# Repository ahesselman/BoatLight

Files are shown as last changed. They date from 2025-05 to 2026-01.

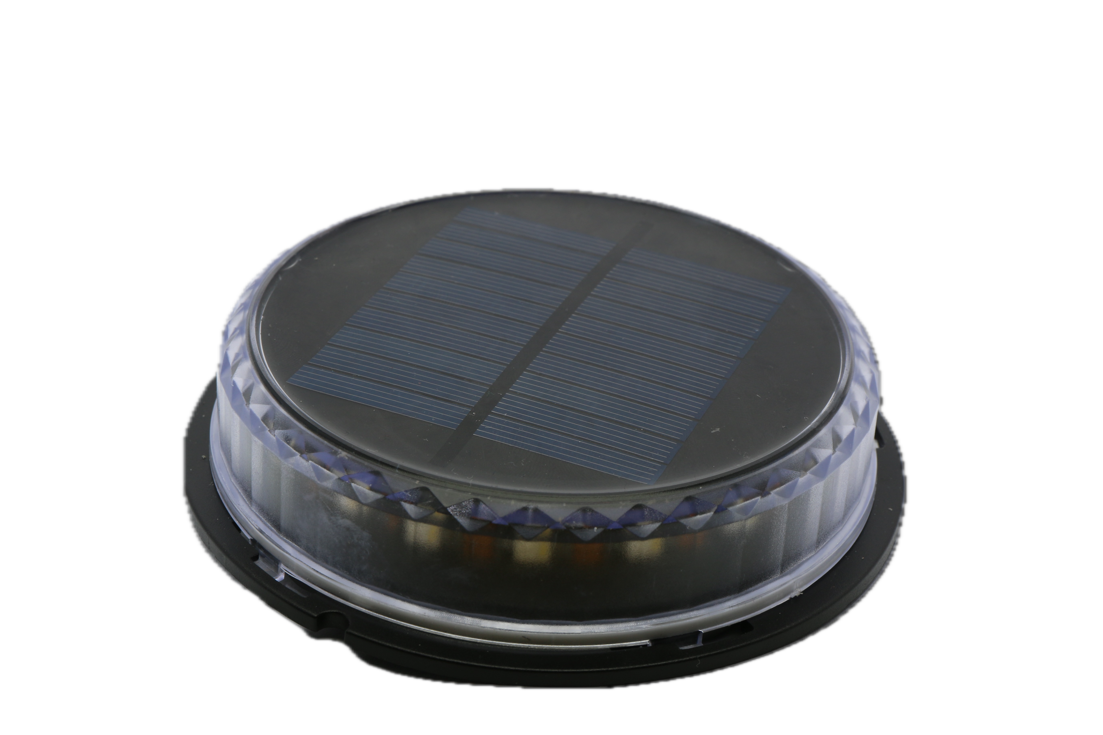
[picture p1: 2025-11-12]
Documents/Images/Lamp.png

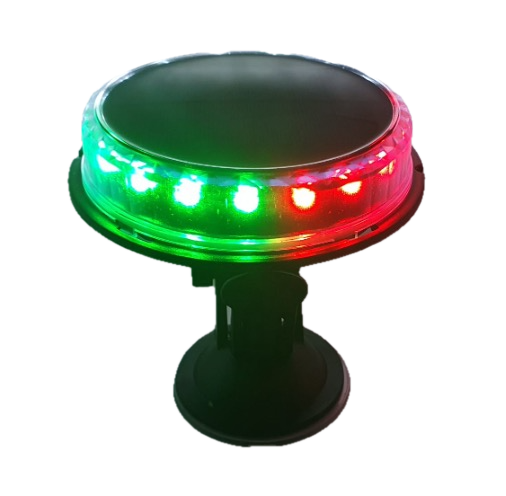
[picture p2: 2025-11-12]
Documents/Images/Lamp On.png

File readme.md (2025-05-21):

# Boat light controller

Controller for a boat light which indicates port and starboard. 

## Description

BoatLight is an LED ring system designed to indicate the port (red) and starboard (green) sides of a boat. It supports eight user-selectable modes, which can be toggled using a physical button. The currently selected mode is saved to persistent storage, so it resumes automatically after a power cycle.

The device is solar-powered. It monitors the voltage from a connected solar panel to determine whether it should be active or idle. When the solar panel voltage drops below 2.35V, the device activates. When the voltage rises above 2.40V, the device enters an idle state to conserve power.

## System overview

* **Power source**: solar panel and USB input
* **Battery**: ?
* **Charging module**: TP4056 for battery charging management
* **Microcontroller**: ATTiny85 for controlling the LEDs and handling user input
* **LEDs**: 16 SK6812 addressable RGBW LEDs
* **User input**: Single push-button for mode selection
* **Power control**: P-channel MOSFET to switch LED power

### Power management

1. Charging circuit

* **TP4056 module**: Connect the solar panel and USB input through appropriate diodes to the TP4056 module's input.
* **Battery connection**: The battery connects to the BAT+ and BAT- terminals of the TP4056.

2. Load sharing

To allow the system to operate while charging and prevent the battery from supplying power when external sources are available, load sharing is implemented

3. Voltage monitoring

A voltage divider is used to monitor the solar panel voltage. This allows the ATTiny85 to detect when the solar voltage drops below 2.35 and activate the LEDs accordingly. To improve stability and prevent unwanted rapid switching, hysterisis is applied. 

### Control circuit

1. ATTiny85 Microcontroller

* **Power supply**: powered from the battery through a voltage regeulator (if necessary).

* **Inputs**:
    * **Voltage divider**: Connected to an ADC pin to monitor solar voltage.
    * **Push-button**: Connected to a digital input pin with a pull-up resistor for mode selection.

* **Outputs**:
    * **LED Control**: A digital output pin connected to the data line of the SK6812 LED strip.
    * **MOSFET control**: A digital output pin to control  the gate of the P-channel MOSFET, switching the LED POWER.

2. P-Channel MOSFET

Used to switch the power for the SK6812 LEDs. The gate is controlled by the the ATTiny85, allowing the microcontroller to disconnect power from the LEDs when not in use, conserving battery life.

## Getting Started

### Dependencies

* Adafruit_NeoPixel

### Setup

* https://www.instructables.com/How-to-Program-an-Attiny85-From-an-Arduino-Uno/

## Authors
LedOptions

### Executing program

## Version History

* 0.1
    * Initial release

## Acknowledgments

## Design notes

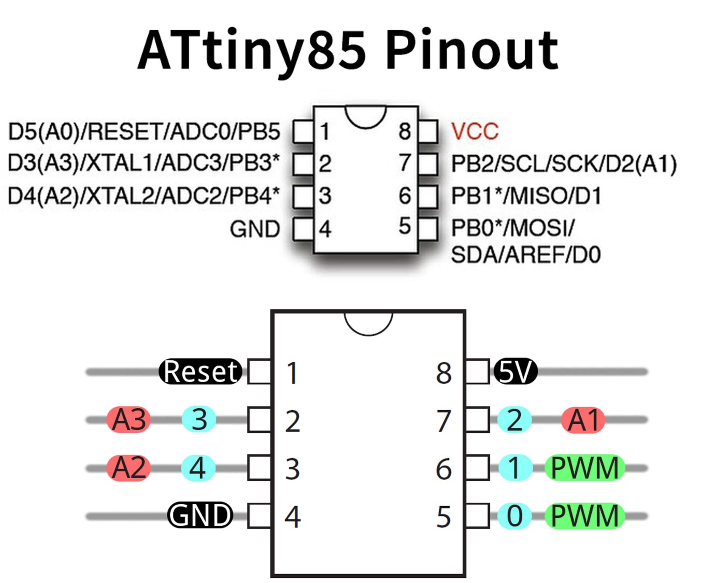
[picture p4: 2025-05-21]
Documents/Images/ATtiny85 pinout.jpg

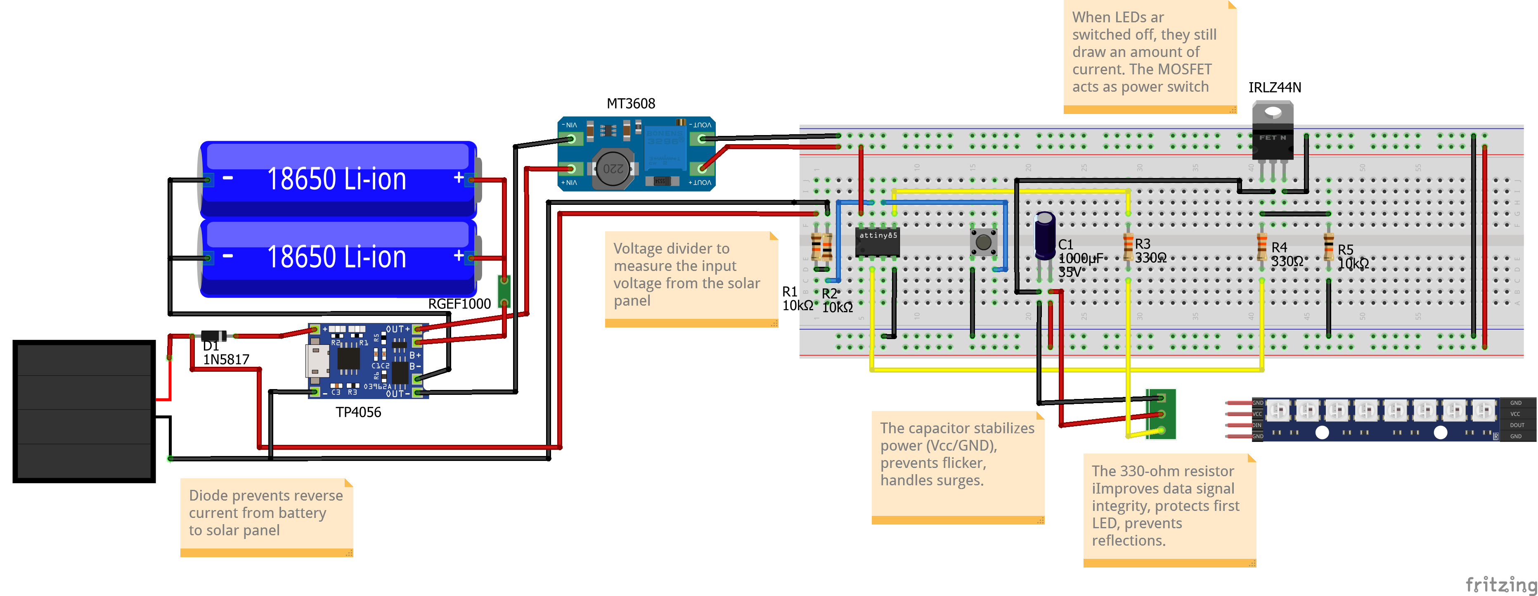
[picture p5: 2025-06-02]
Documents/Images/Sketch.png

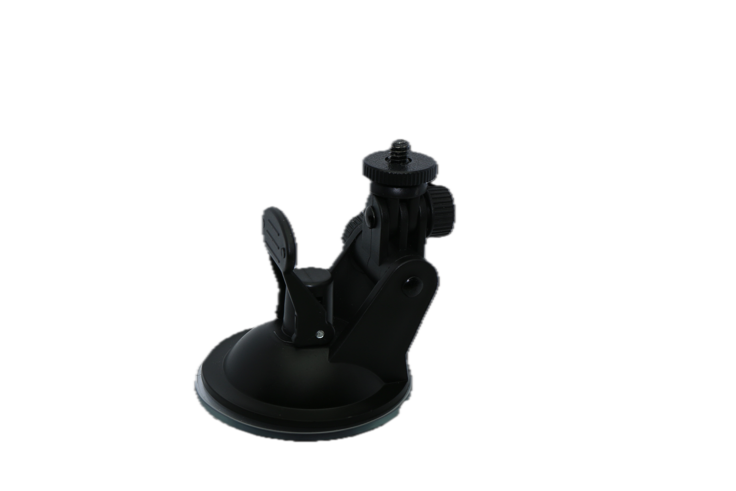
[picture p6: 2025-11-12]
Documents/Images/Stand.png

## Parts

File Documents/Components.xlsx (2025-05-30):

 |  |  |  |  | €23.70
Component | Module | Opmerking | Aantal | Prijs per stuk | Totaal
18650 Cell | Panasonic 3.7V 3200mAh Li-ion Nitecore NL1834 | Beveiliging tegen diepontlading | 2 | €8.95 | €17.90
Charge controller | CN3791 |  |  |  | €0.00
 |  |  |  |  | €0.00
 |  |  |  |  | €0.00
5V 3W zonnepaneel |  |  | 1 | €5.00 | €5.00
Zekering | MR-F110 |  | 1 | €0.80 | €0.80
 |  |  |  |  | €0.00
 |  |  |  |  | €0.00
 |  |  |  |  | €0.00
 |  |  |  |  | €0.00
 |  |  |  |  | €0.00
 |  |  |  |  | €0.00
 |  |  |  |  | €0.00
 |  |  |  |  | €0.00
 |  |  |  |  | €0.00
 |  |  |  |  | €0.00
 |  |  |  |  | €0.00
 |  |  |  |  | €0.00
 |  |  |  |  | €0.00
 |  |  |  |  | €0.00
 |  |  |  |  | €0.00
 |  |  |  |  | €0.00
 |  |  |  |  | €0.00
 |  |  |  |  | €0.00
 |  |  |  |  | €0.00
 |  |  |  |  | €0.00
 |  |  |  |  | €0.00
 |  |  |  |  | €0.00

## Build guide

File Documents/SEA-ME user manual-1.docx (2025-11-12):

SEA-ME

Be Visible

in Marine Environments


Solar/USB charged
Wireless Navigation Light

# Section I - Purpose

These instructions provide guidance on the proper operation and maintenance of the Solar/USB Navigation Light.

# Section II - Description

## 2.1 Introduction

The Solar/USB Navigation Light is a solar- and USB powered signaling device equipped with a built-in 3.7V, 2.6Ah rechargeable lithium battery (approximately 10Wh). It is designed primarily for small leisure vessels but can also be installed on other objects that require position indication or visibility marking.

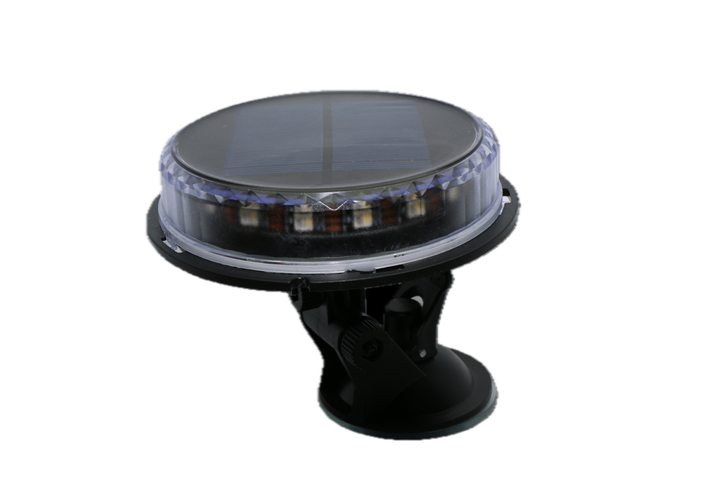
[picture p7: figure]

Figure 1 Solar/USB Navigation Light

The light is wireless, IP66 waterproof, and features three control methods:

1. Manual Power Switch: A main power button allows users to completely switch the light on or off.
2. Light Sensor Switch: An internal light sensor automatically activates the last selected lighting mode at night and turns the light off during daylight, based on ambient light conditions. When turned off due to strong sunlight, the light automatically checks the surrounding brightness every 60 seconds. If the ambient light intensity drops below a preset threshold, the light turns on again automatically.
3. Wireless Remote Control: The included remote control enables users to change light functions conveniently from a distance. Refer to sections 4.1.6 and 4.1.7 for details.

The Solar/USB Navigation Light provides versatile functionality through the remote control. Users can easily switch between multiple modes such as steady light, flashing light, SOS signal, and red/green color options. The last selected function is stored in memory and will automatically reactivate when ambient light conditions trigger the light sensor.

Because the device supports both solar and USB charging, it performs reliably in a wide range of environments. In regions with abundant sunlight, the solar panel ensures efficient charging, while in low-sunlight conditions, the USB-C charging port offers a convenient alternative. The light can also operate when connected to a USB power bank, which simultaneously charges the internal battery.

## 2.2 Product Structure

The Solar/USB Navigation Light consists of the following components: a solar panel, USB-C charging port (for power input only), LED module with lens, built-in 3.7V lithium battery, and an internal control circuit board.

⚠️ Do not attempt to disassemble the light. Refer to section V.

Each unit includes a pre-programmed wireless remote control and a versatile positioning bracket with a ¼–20 thread. Optional accessories include a 15 cm extension rod and additional wireless remotes.

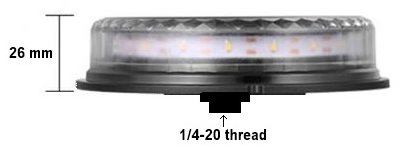
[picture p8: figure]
Afbeelding met licht Door AI gegenereerde inhoud is mogelijk onjuist.
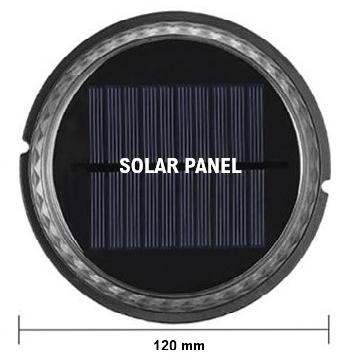
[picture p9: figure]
Afbeelding met cirkel, schermopname Door AI gegenereerde inhoud is mogelijk onjuist.
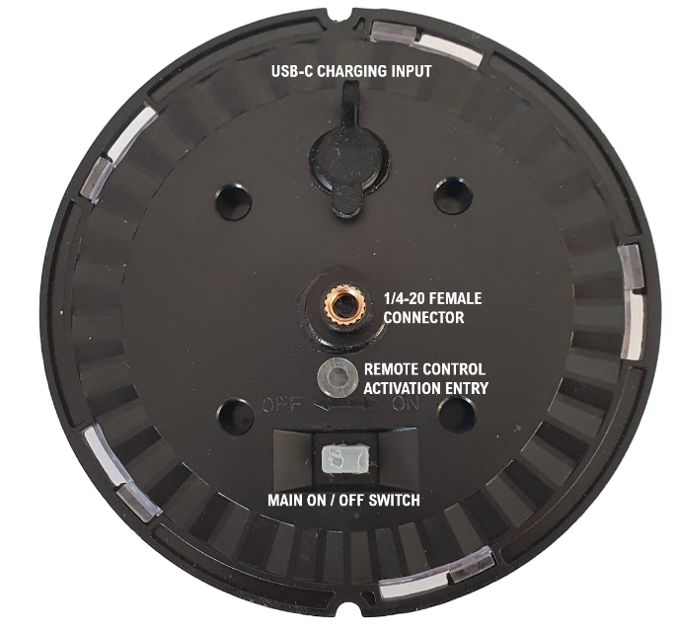
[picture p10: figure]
Afbeelding met cirkel Door AI gegenereerde inhoud is mogelijk onjuist.
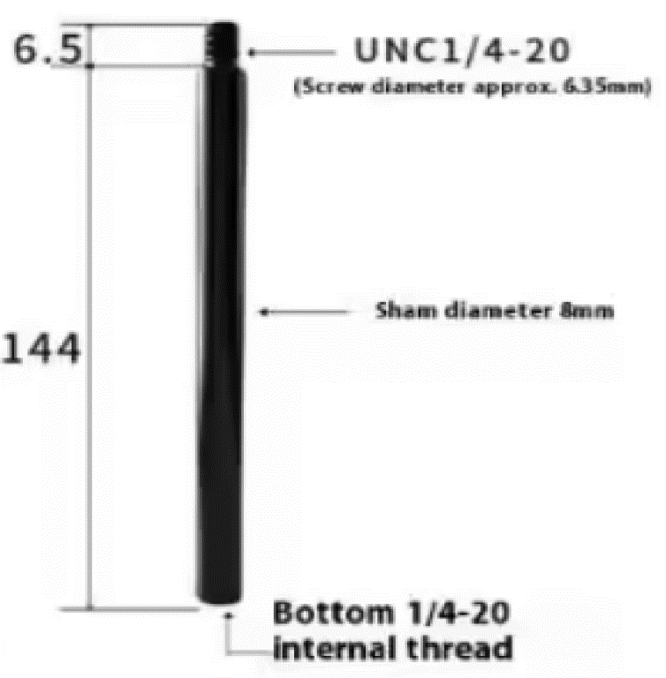
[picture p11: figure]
Afbeelding met tekst, schermopname, Materiaaleigenschap, ontwerp Door AI gegenereerde inhoud is mogelijk onjuist.
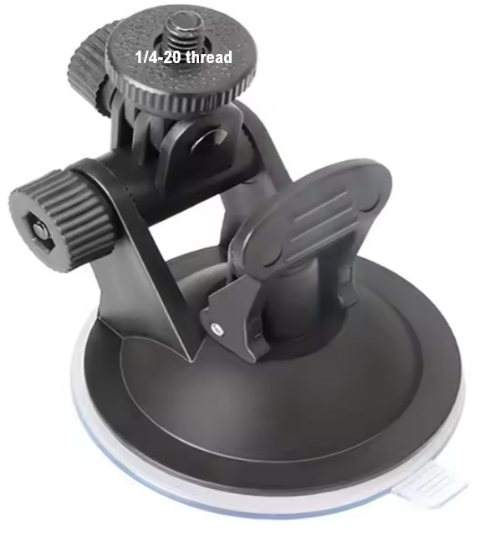
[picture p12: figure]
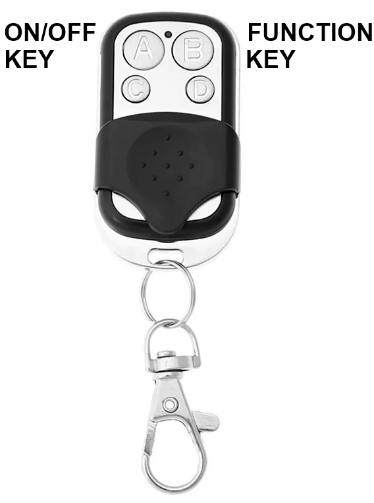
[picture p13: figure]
Afbeelding met Sleutelhanger Door AI gegenereerde inhoud is mogelijk onjuist.

Positioning Bracket, Wireless Remote, Extension Rod (optional)

with suction cup extra remotes optional

## 2.3 Technical Parameters

Parameter | Specification
Light Source | High-intensity LEDs
Primary Activation | Automatic via light sensor
Function Switching | Wireless remote control
Remote Control Range | Over 20 meters (unobstructed)
Battery Type | Built-in rechargeable lithium battery, 3.7V / 2.6Ah (approx. 10Wh)
Charging Methods | - Solar power: Approximately 16 hours of strong sunlight (≈2 clear days) for a full recharge of a depleted battery. - USB-C power: Approximately 8 hours for full recharge.
Power Input Port | USB-C (charging only)
Maximum Wind Resistance | Beaufort Force 12
Operating & Storage Temperature | -30°C to +65°C (-22°F to +149°F)
Dimensions | Main Body: 120 × 26 mm
Weight | Light and Remote: 225 g Bracket and Screws: 120 g
Waterproof Rating | IP66 (remote control not waterproof)
Material Properties | UV-resistant, fire-resistant, oil-resistant, mold-proof, corrosion-proof, waterproof
Certifications | CE and FCC compliant
Warranty | 1 year from date of purchase

## 2.4 Functions

The Solar/USB Navigation Light provides multiple lighting modes suitable for various marine and signaling applications. The functions can be controlled via the wireless remote or the automatic light sensor. The last selected mode is saved in memory and will automatically reactivate when the light sensor detects low ambient light.

Visibility and Performance

Mode/Color | Visibility Range
Green, Red, Bi-Color, Tri-Color | > 1 nautical mile
White (Steady, SOS, Flashing) | > 2 nautical miles

Working Time (Fully Charged Battery)
Flashing Light | > 20 hours
SOS Light | > 20 hours
Steady Light | > 12 hours

Sequence | Function | Description / Typical Use
1 | Green Steady Light | Starboard navigation light
2 | Red Steady Light | Port navigation light
3 | Red & Green Steady Light | Bi-color navigation light
4 | White Stern Steady Light | Stern visibility light
5 | White Steam Steady Light | Forward-facing navigation light
6 | Red, Green & White Steady Light | Tri-color navigation light
7 | White 360° Steady Light | Anchor or all-round light
8 | White 360° SOS Light | Distress or emergency signal
9 | White 360° Flashing Light | Position or attention light

Notes:

- The visibility range and working time are based on a fully charged battery under standard test conditions.
- Continuous operation of steady light modes for extended periods may reduce overall battery lifespan.
- The light automatically resumes the last active mode when ambient light falls below the preset brightness threshold.

# Section III - Installation Instructions

## 3.1 Compatibility

The Solar/USB Navigation Light is suitable for installation on a wide range of objects requiring position indication or visibility marking, such as:

- Yachts, fishing boats, and leisure craft
- Docks and marinas
- Buoys, markers, or floating equipment
- Gardens, walkways, and building exteriors

For optimal performance, install the light in a location with unobstructed sunlight exposure or ensure access to a USB power source when solar charging is limited.

## 3.2 Installation Guidelines

### 3.2.1 General Positioning

Install the Solar/USB Navigation Light on the topmost point of a vessel, structure, or mounting surface to ensure maximum visibility from all directions.

### 3.2.2 Mounting Procedure

1. Ensure the mounting surface is clean, dry, and flat.
2. Attach the light to the positioning bracket using the threaded connector (¼–20 thread).
3. Set the lever on the positioning bracket to the upward position.
4. Place the bracket on the desired surface and push the lever down to create a vacuum seal with the suction cup.
5. Adjust the bracket to achieve the desired angle and direction for optimal visibility.

⚠️ Caution:

- Ensure the suction cup is securely attached before use.
- Do not install the light near moving parts, exhaust outlets, or heat sources.
- In high-vibration or long-term installations, consider additional mechanical fastening to prevent detachment.

## 3.3 Environmental Considerations

- Position the light where it receives direct sunlight for most of the day to maintain full charging efficiency.
- Avoid installing under shaded areas, awnings, or metal structures that may block sunlight.
- If used in saltwater environments, periodically rinse the bracket and suction cup with fresh water to prevent salt buildup and maintain adhesion strength.

# Section IV - Operation & Usage Instructions

## 4.1 Operation Instructions

### 4.1.1 Powering On

After installation, switch the main POWER button on the light to the “ON” position.

Pressing the “ON/OFF” button (A) on the wireless remote control to activate and deactivate the device while in operation.

### 4.1.2 Selecting Light Functions

Press the “FUNCTION SWITCH” button (B) on the remote control to cycle through the available lighting modes. Refer to Section 2.4 for the complete sequence and description of each function.

### 4.1.3 Automatic Light Sensor Operation

When the device is turned on, the light sensor is always active. The light will automatically turn on at night and switches off during the day based on ambient brightness.
When the light is turned off due to strong sunlight, it performs an ambient light check every ~ 60 seconds.
If the light intensity drops below the preset threshold, the light automatically turns on again using the last selected mode.

### 4.1.4 Solar Charging

When exposed to sunlight, the built-in solar panel charges the internal battery whether the light is switched on or off.

- A full solar charge typically requires about 16 hours of strong sunlight (≈ two clear days).
- Working time varies by mode:
  - Flashing / SOS light: > 20 hours
  - Steady light: > 12 hours

💡 Tip:
To prevent power depletion, avoid using steady light continuously for more than 12 hours without adequate charging intervals.

### 4.1.5 USB Charging

The light can also be charged via the USB-C port located at the bottom of the housing.

- A fully depleted battery will recharge in approximately 8 hours via USB.
- The light can operate while charging from a USB power bank or power supply.

### 4.1.6 Remote Control Operation

- The wireless remote operates at a distance of over 20 meters (without obstruction).
- If the LED indicator on the remote becomes weak, replace the battery.
- The remote control is not waterproof—keep it dry and avoid exposure to moisture.

### 4.1.7 Remote Pairing

Each remote is pre-paired with the corresponding light.
If the original remote is lost or replaced, follow these steps to pair a new remote:

1. Remove the small plug labeled “REMOTE CONTROL ACTIVATION ENTRY” at the bottom of the light.
2. Press the internal button using a small screwdriver.
3. Press the “A” button on the new remote control to complete pairing.
4. Reinsert the plug firmly to maintain waterproof integrity.

Multiple remotes can be paired with the same light to enable synchronized control.

## 4.2 Usage Instructions

### 4.2.1 Position Indication

Use the flashing mode to indicate the vessel’s position or to enhance visibility in low-light conditions.

### 4.2.2 Emergency Signaling

Activate the SOS mode in emergency or distress situations to broadcast a visual alert visible from over two nautical miles.

### 4.2.3 Anchor and Auxiliary Lighting

The white steady light can serve as an anchor light or general-purpose illumination in leisure or docking scenarios.

### 4.2.4 Usage Limitations

⚠️ Important Notice:
This product is not a certified navigation light and must not be used as a replacement for standard, regulation-compliant marine navigation lights.
It is suitable for leisure use and for vessels under 20 meters in length, or as a supplementary lighting device.

# Section V - Service Life & Safety

## 5.1 Product Warranty

The Solar/USB Navigation Light is covered by a one-year limited warranty from the date of purchase.
The warranty applies to defects in materials or workmanship under normal operating conditions and proper use.

The warranty does not cover:

- Damage caused by misuse, neglect, impact, or unauthorized modification
- Water damage resulting from improper sealing or removal of protective components
- Normal wear and tear or battery degradation over time

For warranty claims or technical assistance, contact your authorized dealer or distributor with proof of purchase.

## 5.2 Safety Precautions

The Solar/USB Navigation Light contains a rechargeable lithium battery and electronic components that require careful handling.
Please observe the following safety instructions:

1. Do not disassemble or modify the product or battery.
2. Do not incinerate or expose the light to open flames or excessive heat.
3. Avoid short-circuiting the battery terminals or USB-C connector.
4. Store and operate the device within the temperature range of -30°C to +65°C (-22°F to +149°F).
5. Do not immerse the wireless remote in water—it is not waterproof.
6. Keep the product away from children unless supervised by an adult.
7. Avoid direct eye exposure to the LED light when operating at close range.
8. Dispose of the product and battery in accordance with local environmental regulations (see section 8.2).

⚠️ Warning:
Mishandling lithium batteries may cause overheating, leakage, fire, or explosion.
Always follow these safety instructions to prevent injury or equipment damage.

# Section VI - Inspection

## 6.1 Routine Inspection

To ensure optimal performance and a long service life, inspect the Solar/USB Navigation Light regularly.
Perform the following checks every 3–6 months, depending on environmental conditions and frequency of use:

- Clean the solar panel, light sensor, and lens with a soft cloth to remove dust, salt, or debris. This improves sunlight absorption and ensures accurate light sensing.
- Check the bracket and suction cup for secure attachment and signs of wear.
- Verify remote functionality by testing all light modes and control distance.
- Inspect for visible damage to the housing, solar panel, or charging port.

💡 Tip:
Regular cleaning and inspection significantly enhance solar charging efficiency and overall reliability.

## 6.2 Performance Check

If the light fails to operate correctly:

1. Set the main POWER switch to the off position to switch the light off.
2. To ensure complete recharging, either:
  1. Expose the device to direct sunlight for at least 2 full days
  2. Connect the device it via the USB-C port to a power source for at least 8 hours
3. Turn the light back on and test functionality using the remote control.

If the problem persists, verify that the USB-C port, cable and remote control are functioning correctly before contacting service support.

## 6.3 Remote Control Troubleshooting

If the wireless remote does not respond:

- Replace the remote battery and retry.
- Re-pair the remote with the light following the procedure in Section 4.1.7.
- Ensure there are no obstacles or metallic surfaces between the remote and the light during operation.

⚠️ Note:
The remote control is not waterproof. Exposure to moisture may cause malfunction. If the remote becomes wet, dry it thoroughly before use.

# Section VII - Maintenance

The Solar/USB Navigation Light is designed to be virtually maintenance-free. However, basic care and periodic checks are recommended to maintain optimal performance and extend the product’s service life.

## 7.1 Storage Conditions

- Store the device in a cool, dry place away from direct sunlight when not in use.
- Keep the original packaging intact to protect the light during storage or transportation.
- Avoid placing heavy objects on top of the packaged product.

## 7.2 Battery Maintenance

- Recharge the light to 50% at least once every 3 months during periods of storage or inactivity to maintain battery health.
- If the light is stored for longer than 3 months, place it in direct sunlight for at least 8 hours before use to ensure battery capacity.
- Avoid long-term storage with a completely discharged battery, as this may shorten the battery’s lifespan.

## 7.3 Solar Charging Guidelines

- The solar charging efficiency depends on weather, sunlight angle, and environmental conditions.
- For best performance, position the light so that the solar panel faces direct sunlight for most of the day.
- Continuous operation of the steady light mode should not exceed 12 hours per day to prevent over-discharge of the battery.

## 7.4 Performance Notes

- The stated working hours are based on a fully charged battery and typical environmental conditions during the first year of use.
- Over time, battery capacity and runtime may gradually decrease — this is a normal characteristic of lithium batteries.

# Section VIII - Repair & Disposal Instructions

## 8.1 Repair Instructions

The Solar/USB Navigation Light is not designed to be disassembled or repaired by the user.

- If the light fails to function properly within the one-year warranty period, contact your authorized dealer or manufacturer for assistance.
- The warranty covers defects in materials or workmanship under normal use.
- For products that fail after the warranty period, users should purchase a replacement unit rather than attempting repairs.

⚠️ Warning:
Attempting to open or modify the light or its battery may cause irreversible damage, electrical shock, or fire hazard.

## 8.2 Disposal Instructions

To protect the environment and comply with local regulations:

1. Do not dispose of the light or its lithium battery in household waste.
2. Take used, defective, or expired products to an approved recycling or electronic waste facility.
3. Follow all local environmental and safety regulations regarding lithium batteries and electronic components.

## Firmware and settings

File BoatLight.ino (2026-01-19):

#include <Adafruit_NeoPixel.h>
#include <Bounce2.h>
#include <EEPROM.h>
#include <avr/sleep.h>
#include <avr/wdt.h>

#ifdef __AVR__
#include <avr/power.h>
#endif

// ------------------------------------------------------------
// Pin definitions (ATtiny85 internal vs. external pins)
// ------------------------------------------------------------
//                             RST    - pin 1
#define BUTTON_SOS_PIN 3    // PB3    - pin 2
#define BUTTON_ON_OFF_PIN 4 // PB4    - pin 3 (a on remote)
                            // GND    - Pin 4
#define LED_PIN 0           // PB0    - pin 5
#define BUTTON_MODE_PIN 1   // PB1    - pin 6 (b on remote)
#define VOLTAGE_PIN A1      // PB2    - pin 7
                            // VCC    - pin 8

#define SOS_LETTERS 3

// ------------------------------------------------------------
// Enums
// ------------------------------------------------------------
enum LightMode
{
  GREEN = 0,
  RED,
  GREEN_RED,
  WHITE_FRONT,
  WHITE_BACK,
  FULL_COMBO,
  WHITE_ALL,
  FLASH,
  SOS,       // <-- always thrid to last, will only be activated when pressing sos button
  OFF_MODE,  // <-- always second to last, will only be activated when pressing on/off button
  MODE_COUNT // <-- always last — auto-updates
};

enum LedStripWhiteSectorMode
{
  FRONT = 0,
  BACK
};

// ------------------------------------------------------------
// Constants
// ------------------------------------------------------------
const uint8_t numberOfLeds = 17;
const uint8_t numberOfModes = LightMode::MODE_COUNT;
const byte sleepTime = 0b100001; // 8 seconds
const uint8_t sleepCycles = 4;   // 4 cycles * 8 seconds = 32 seconds total
const unsigned long saveDelayDuration = 3000;
const uint8_t maxBrightness = 255;
const uint8_t maxBrightnessWhite = 165;
const float colorDegrees = 112.5;
const float voltageLowerThreshold = 1.75;
const float voltageUpperThreshold = 3.25;
const float resistor1Value = 10000.0;
const float resistor2Value = 10000.0;
constexpr float referenceVoltage = 5.0;
constexpr float dividerFactor = referenceVoltage / 1023.0;

/* -- Morse timing constants --
    1. The length of a dot is 1 time unit.
    2. A dash is 3 time units.
    3. The space between symbols (dots and dashes) of the same letter is 1 time unit.
    4. The space between letters is 3 time units.
    5. The space between words is 7 time units.
*/
const uint16_t morseTimeUnit = 250;
const uint16_t symbolPauseDuration = 1 * morseTimeUnit;
const uint16_t letterPauseDuration = 3 * morseTimeUnit;
const uint16_t wordPauseDuration = 7 * morseTimeUnit;

const uint8_t sosPattern[][4] PROGMEM = {
    {1, 1, 1, 0}, // S = dot dot dot
    {3, 3, 3, 0}, // O = dash dash dash
    {1, 1, 1, 0}  // S = dot dot dot
};

// ------------------------------------------------------------
// Data structures
// ------------------------------------------------------------
struct LedStripSectors
{
  uint8_t red[numberOfLeds];
  uint8_t green[numberOfLeds];
  uint8_t whiteBack[numberOfLeds];
  uint8_t whiteFront[numberOfLeds];

  uint8_t redCount;
  uint8_t greenCount;
  uint8_t whiteBackCount;
  uint8_t whiteFrontCount;
};

// ------------------------------------------------------------
// Globals
// ------------------------------------------------------------
bool shouldResetStrip = false;
bool sosInitialized = false;
uint8_t currentMode = LightMode::OFF_MODE;
uint8_t lastActiveMode = LightMode::GREEN;
unsigned long lastModeChangeTime = 0;
unsigned long pressStartTime = 0;
uint8_t sosPatternStepIndex = 0;
unsigned long sosLastTime = 0;

LedStripSectors ledStripSectors;

Adafruit_NeoPixel ledStrip(numberOfLeds, LED_PIN, NEO_GRBW + NEO_KHZ800);

Bounce2::Button modeButton = Bounce2::Button();
Bounce2::Button onOffButton = Bounce2::Button();
Bounce2::Button sosButton = Bounce2::Button();

// ------------------------------------------------------------
// Function Declarations
// ------------------------------------------------------------
void initializeAndTestLedStrip();
void initializeLedStripSectors();
void initializeButton(Bounce2::Button &button, uint8_t pin, uint16_t interval = 25);
void readAndSanitizeStoredMode();

void handleOnOffButtonPress();
void handleModeButtonPress();
void handleSosButtonPress();
void storeCurrentMode();

float readSolarVoltage();
void performAndHandleVoltageRead();
void handleVoltageState(float voltage);
void handleLowVoltage();
void handleHighVoltage();

void applyCurrentMode(uint8_t mode);
void showRed();
void showGreen();
void showWhite(LedStripWhiteSectorMode mode);
void colorLedsInRange(uint8_t start, uint8_t end, uint8_t r, uint8_t g, uint8_t b, uint8_t w, bool reset);
void handleSosAnimation();
void handleFlashMode();
void setAllWhite(uint8_t brightness, bool doShow = true, bool setBrightnessFlag = true);
void handleOffMode();

void shutDownWithWD(uint8_t wdt_period);

// ------------------------------------------------------------
// Setup
// ------------------------------------------------------------
void setup()
{
#if defined(__AVR_ATtiny85__) && (F_CPU == 16000000)
  clock_prescale_set(clock_div_1);
#endif

  initializeAndTestLedStrip();
  initializeLedStripSectors();
  initializeButton(modeButton, BUTTON_MODE_PIN);
  initializeButton(onOffButton, BUTTON_ON_OFF_PIN);
  initializeButton(sosButton, BUTTON_SOS_PIN);
  readAndSanitizeStoredMode();
}

// ------------------------------------------------------------
// Loop
// ------------------------------------------------------------
void loop()
{
  handleOnOffButtonPress();
  handleModeButtonPress();
  handleSosButtonPress();
  storeCurrentMode();
  performAndHandleVoltageRead();
}

// ------------------------------------------------------------
// LED Strip Setup and Test
// ------------------------------------------------------------
void initializeAndTestLedStrip()
{
  ledStrip.begin();
  ledStrip.clear();
  ledStrip.show();

  ledStrip.setBrightness(maxBrightness);

  for (uint8_t i = 0; i < numberOfLeds; i++)
  {
    ledStrip.clear();
    ledStrip.setPixelColor(i, ledStrip.Color(0, 0, 0, maxBrightness));
    ledStrip.show();
    delay(50);
  }

  setAllWhite(maxBrightness);

  delay(200);

  for (uint8_t b = maxBrightness; b > 0; b -= 15)
  {
    ledStrip.setBrightness(b);
    ledStrip.show();
    delay(20);
  }

  ledStrip.clear();
  ledStrip.show();

  ledStrip.setBrightness(maxBrightness);
}

// ------------------------------------------------------------
// LED Sector Setup
// ------------------------------------------------------------
void initializeLedStripSectors()
{
  ledStripSectors.redCount = 0;
  ledStripSectors.greenCount = 0;
  ledStripSectors.whiteFrontCount = 0;
  ledStripSectors.whiteBackCount = 0;

  float degreesPerLed = 360.0 / numberOfLeds;
  uint8_t numberColoredLeds = round(colorDegrees / degreesPerLed);

  for (uint8_t i = 0; i < numberColoredLeds; i++)
  {
    ledStripSectors.green[ledStripSectors.greenCount++] = i;
  }

  for (uint8_t i = 0; i < numberColoredLeds; i++)
  {
    ledStripSectors.red[ledStripSectors.redCount++] = numberColoredLeds + i;
  }

  uint8_t numberWhiteLeds = numberOfLeds - (2 * numberColoredLeds);
  uint8_t startIdOfWhiteLed = 2 * numberColoredLeds;

  for (uint8_t i = 0; i < numberWhiteLeds; i++)
  {
    ledStripSectors.whiteBack[ledStripSectors.whiteBackCount++] = startIdOfWhiteLed + i;
  }

  for (uint8_t i = 0; i < numberColoredLeds * 2; i++)
  {
    ledStripSectors.whiteFront[ledStripSectors.whiteFrontCount++] = i;
  }
}

// ------------------------------------------------------------
// Button Setup
// ------------------------------------------------------------
void initializeButton(Bounce2::Button &button, uint8_t pin, uint16_t interval)
{
  button.attach(pin, INPUT);
  button.interval(interval);
  button.setPressedState(HIGH);
}

// ------------------------------------------------------------
// Fetch Stored Mode
// ------------------------------------------------------------
void readAndSanitizeStoredMode()
{
  uint8_t stored = EEPROM.read(0);
  if (stored >= numberOfModes)
    stored = LightMode::GREEN;
  currentMode = stored;
  lastActiveMode = stored;
}

// ------------------------------------------------------------
// Button Handling
// ------------------------------------------------------------

void handleOnOffButtonPress()
{
  onOffButton.update();
  if (!onOffButton.rose())
    return;

  if (currentMode != LightMode::OFF_MODE)
  {
    lastActiveMode = currentMode;
    currentMode = LightMode::OFF_MODE;
  }
  else
  {
    currentMode = lastActiveMode;
  }
  shouldResetStrip = true;
}

void handleModeButtonPress()
{
  modeButton.update();
  if (!modeButton.rose())
    return;

  uint8_t nextMode = lastActiveMode;

  do
  {
    nextMode = (nextMode + 1) % (numberOfModes - 1); // last mode is OFF_MODE
  } while (nextMode == LightMode::SOS);

  currentMode = nextMode;
  lastActiveMode = currentMode;
  shouldResetStrip = true;
  lastModeChangeTime = millis();
}

void handleSosButtonPress()
{
  sosButton.update();
  if (!sosButton.rose())
    return;

  if (currentMode != LightMode::SOS)
  {
    lastActiveMode = currentMode; // store current mode to return to
    currentMode = LightMode::SOS;
  }
  else
  {
    currentMode = lastActiveMode; // toggle off SOS
  }

  shouldResetStrip = true;
}

// ------------------------------------------------------------
// EEPROM Mode Saving
// ------------------------------------------------------------
void storeCurrentMode()
{
  if (currentMode != LightMode::OFF_MODE &&
      millis() - lastModeChangeTime > saveDelayDuration &&
      EEPROM.read(0) != currentMode)
  {
    EEPROM.update(0, currentMode);
  }
}

// ------------------------------------------------------------
// Voltage Reading & Power Control
// ------------------------------------------------------------
void performAndHandleVoltageRead()
{
  float solarVoltage = readSolarVoltage();
  handleVoltageState(solarVoltage);
}

float readSolarVoltage()
{
  long sum = 0;
  for (int i = 0; i < 10; i++)
  {
    sum += analogRead(VOLTAGE_PIN);
    delay(2);
  }
  float avg = sum / 10.0;
  float voltageAtPin = avg * dividerFactor;
  return voltageAtPin * ((resistor1Value + resistor2Value) / resistor2Value);
}

void handleVoltageState(float voltage)
{
  if (voltage < voltageLowerThreshold)
  {
    handleLowVoltage();
  }
  else if (voltage > voltageUpperThreshold)
  {
    handleHighVoltage();
  }
}

void handleLowVoltage()
{
  applyCurrentMode(currentMode);
}

void handleHighVoltage()
{
  ledStrip.clear();
  ledStrip.show();

  for (int j = 0; j < sleepCycles; j++)
  {
    shutDownWithWD(sleepTime);
  }
}

// ------------------------------------------------------------
// LED Modes
// ------------------------------------------------------------
void applyCurrentMode(uint8_t mode)
{
  switch (mode)
  {
  case LightMode::GREEN:
    showGreen();
    break;
  case LightMode::RED:
    showRed();
    break;
  case LightMode::GREEN_RED:
    showGreen();
    showRed();
    break;
  case LightMode::WHITE_FRONT:
    showWhite(FRONT);
    break;
  case LightMode::WHITE_BACK:
    showWhite(BACK);
    break;
  case LightMode::FULL_COMBO:
    showGreen();
    showRed();
    showWhite(BACK);
    break;
  case LightMode::WHITE_ALL:
    setAllWhite(maxBrightnessWhite);
    break;
  case LightMode::SOS:
    handleSosAnimation();
    break;
  case LightMode::FLASH:
    handleFlashMode();
    break;
  case LightMode::OFF_MODE:
  default:
    handleOffMode();
    break;
  }

  if (mode != LightMode::SOS && sosInitialized)
    sosInitialized = false;

  if (mode != LightMode::SOS && mode != LightMode::FLASH)
    ledStrip.show();
}

// ------------------------------------------------------------
// SOS Mode
// ------------------------------------------------------------
void handleSosAnimation()
{
  static unsigned long lastActionTime = 0;
  static uint8_t letterIndex = 0;
  static uint8_t symbolIndex = 0;
  static bool ledOn = false;
  static uint16_t currentDelay = 0;

  if (currentMode != LightMode::SOS)
  {
    sosInitialized = false;
    return;
  }

  unsigned long now = millis();

  if (!sosInitialized)
  {
    sosInitialized = true;
    letterIndex = 0;
    symbolIndex = 0;
    ledOn = false;
    lastActionTime = now;
    currentDelay = 0;

    ledStrip.setBrightness(maxBrightness);
    ledStrip.clear();
    ledStrip.show();
    return;
  }

  if (now - lastActionTime < currentDelay)
  {
    return;
  }

  if (!ledOn)
  {
    uint8_t unit = pgm_read_byte(&sosPattern[letterIndex][symbolIndex]);

    if (unit == 0)
    {
      letterIndex++;
      symbolIndex = 0;

      if (letterIndex >= SOS_LETTERS)
      {
        // end of word; start over after word gap
        letterIndex = 0;
        lastActionTime = now;
        currentDelay = wordPauseDuration;
        ledStrip.clear();
        ledStrip.show();
        return;
      }
      else
      {
        // letter gap
        lastActionTime = now;
        currentDelay = letterPauseDuration;
        ledStrip.clear();
        ledStrip.show();
        return;
      }
    }

    setAllWhite(maxBrightness, true, false);
    ledOn = true;
    lastActionTime = now;
    currentDelay = (uint16_t)unit * morseTimeUnit;
    symbolIndex++;
    return;
  }

  if (ledOn)
  {
    ledStrip.clear();
    ledStrip.show();
    ledOn = false;
    lastActionTime = now;
    currentDelay = symbolPauseDuration;
  }
}

// ------------------------------------------------------------
// FLASH Mode
// ------------------------------------------------------------
void handleFlashMode()
{
  static unsigned long lastFlashTime = 0;
  static bool flashOn = false;
  unsigned long now = millis();

  if (now - lastFlashTime >= 500)
  {
    lastFlashTime = now;
    flashOn = !flashOn;
    if (flashOn)
      setAllWhite(maxBrightness);
    else
    {
      ledStrip.clear();
      ledStrip.show();
    }
  }
}

// ------------------------------------------------------------
// Helpers
// ------------------------------------------------------------
void setAllWhite(uint8_t brightness, bool doShow, bool setBrightnessFlag)
{
  if (setBrightnessFlag)
    ledStrip.setBrightness(brightness);

  for (int i = 0; i < numberOfLeds; i++)
  {
    ledStrip.setPixelColor(i, ledStrip.Color(0, 0, 0, 255));
  }

  if (doShow)
    ledStrip.show();
}

void showRed()
{
  if (ledStripSectors.redCount == 0)
    return;
  uint8_t first = ledStripSectors.red[0];
  uint8_t last = ledStripSectors.red[ledStripSectors.redCount - 1];
  if (first > last || last >= numberOfLeds)
    return;
  colorLedsInRange(first, last, 255, 0, 0, 0, shouldResetStrip);
  shouldResetStrip = false;
}

void showGreen()
{
  if (ledStripSectors.greenCount == 0)
    return;
  uint8_t first = ledStripSectors.green[0];
  uint8_t last = ledStripSectors.green[ledStripSectors.greenCount - 1];
  if (first > last || last >= numberOfLeds)
    return;
  colorLedsInRange(first, last, 0, 255, 0, 0, shouldResetStrip);
  shouldResetStrip = false;
}

void showWhite(LedStripWhiteSectorMode mode)
{
  uint8_t first = 0, last = 0;
  if (mode == BACK)
  {
    first = ledStripSectors.whiteBack[0];
    last = ledStripSectors.whiteBack[ledStripSectors.whiteBackCount - 1];
  }
  else
  {
    first = ledStripSectors.whiteFront[0];
    last = ledStripSectors.whiteFront[ledStripSectors.whiteFrontCount - 1];
  }
  colorLedsInRange(first, last, 0, 0, 0, maxBrightnessWhite, shouldResetStrip);
  shouldResetStrip = false;
}

void colorLedsInRange(uint8_t start, uint8_t end, uint8_t r, uint8_t g, uint8_t b, uint8_t w, bool reset)
{
  if (start >= numberOfLeds || end >= numberOfLeds)
    return;
  if (start > end)
    return;

  if (reset)
  {
    ledStrip.clear();
    ledStrip.setBrightness(maxBrightness);
  }
  for (int i = start; i <= end; i++)
  {
    ledStrip.setPixelColor(i, ledStrip.Color(r, g, b, w));
  }
}

void handleOffMode()
{
  ledStrip.clear();
  ledStrip.show();
}

// ------------------------------------------------------------
// Watchdog Sleep
// ------------------------------------------------------------
ISR(WDT_vect) { wdt_disable(); }

void shutDownWithWD(uint8_t wdt_period)
{
  noInterrupts();
  wdt_reset();

  MCUSR = 0;
#if defined(WDTCSR)
  WDTCSR = (1 << WDCE) | (1 << WDE); // Old vs new cores compatible
  WDTCSR = (1 << WDIE) | wdt_period;
#elif defined(WDTCR)
  WDTCR = (1 << WDCE) | (1 << WDE);
  WDTCR = (1 << WDIE) | wdt_period;
#else
#error "Watchdog Timer register not defined for this MCU!"
#endif

  // Disable ADC and peripherals
  ADCSRA &= ~(1 << ADEN);
  power_all_disable();

  set_sleep_mode(SLEEP_MODE_PWR_DOWN);
  sleep_bod_disable();

  interrupts();
  sleep_mode(); // sleep until WDT interrupt

  // wakes here
  power_all_enable();
  _delay_ms(10);
  ADCSRA |= (1 << ADEN);
}

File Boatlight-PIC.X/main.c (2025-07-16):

// CONFIG
#pragma config FOSC = INTRCIO
#pragma config WDTE = OFF
#pragma config PWRTE = OFF
#pragma config MCLRE = OFF
#pragma config BOREN = OFF
#pragma config CP = OFF
#pragma config CPD = OFF

#include <xc.h>
#include <stdbool.h>

#define _XTAL_FREQ          4000000

// Pin definitions
#define SECTION_RED         GP0
#define SECTION_GREEN       GP1
#define SECTION_WHITE_01_10 GP2
#define SECTION_WHITE_11_16 GP3
#define BUTTON              GP4

typedef enum {
    OFF = 0,
    RED_GREEN,
    WHITE_01_10,
    WHITE_11_16,
    FULL_COMBO,
    ALL_WHITE,
    ALL_WHITE_FLASH,
    ALL_WHITE_SOS,
    STATE_MAX
} SystemState;

volatile unsigned int msTicks       = 0;
volatile unsigned int flash_timer   = 0;
volatile unsigned int sos_timer     = 0;
volatile unsigned char sos_index    = 0;
volatile bool sosState              = false;
volatile bool flashState            = false;

// Morse code pattern: 1 = short (200ms), 3 = long (600ms), 0 = OFF
const unsigned char sos_pattern[] = {
    1,0, 1,0, 1,0,    // S
    3,0, 3,0, 3,0,    // O
    1,0, 1,0, 1,0,    // S
    0                // End
};

SystemState state = FULL_COMBO;

void resetSections(void) {
    SECTION_RED = 0;
    SECTION_GREEN = 0;
    SECTION_WHITE_01_10 = 0;
    SECTION_WHITE_11_16 = 0;
}

// === TIMER0 ISR ===
void __interrupt() isr(void) {
    if (T0IF) {
        T0IF = 0;             // Clear interrupt flag
        TMR0 = 256 - 250;     // Preload for ~1ms tick
        msTicks++;

        // Flash for ALL_WHITE_FLASH state
        if (++flash_timer >= 500) {
            flash_timer = 0;
            flashState = !flashState;
        }

        // SOS logic
        if (state == ALL_WHITE_SOS) {
            unsigned int duration = (sos_pattern[sos_index] == 1) ? 200 :
                                    (sos_pattern[sos_index] == 3) ? 600 : 0;

            sos_timer++;
            if (sos_timer >= duration) {
                sos_timer = 0;
                sosState = !sosState;
                sos_index++;
                if (sos_pattern[sos_index] == 0) sos_index = 0;
            }
        }
    }
}

void setupTimer0(void) {
    OPTION_REG = 0b00000111;  // Prescaler 1:256, assigned to TMR0
    TMR0 = 256 - 250;         // ~1ms at 4MHz
    T0IE = 1;                 // Enable Timer0 interrupt
    GIE = 1;                  // Enable global interrupts
}

void main(void) {
    TRISIO = 0b00010000;   // GP4 = input (button), others = output
    CMCON = 0x07;          // Disable comparator (enables digital I/O)
    GPIO = 0x00;
    WPU = 0b00010000;      // Pull-up on GP4
    OPTION_REGbits.nGPPU = 0;  // Enable pull-ups

    setupTimer0();

    unsigned char lastButton = 1; 
    unsigned long button_pressed_time = 0;
    bool button_held = false;
    unsigned int cycle_state_timer = 0;
    SystemState last_active_state = FULL_COMBO;

    while (1) {
        // Read current button state
        unsigned char button = BUTTON;

        // Detect falling edge (button just pressed)
        if (button == 0 && lastButton == 1) {
            button_pressed_time = msTicks;
            button_held = false;
        }

        // Button held
        if (button == 0 && !button_held) {
            if ((msTicks - button_pressed_time) >= 1000) {  // 1 sec = long press
                button_held = true;
                cycle_state_timer = msTicks;
                // Skip OFF state
                if (state == OFF) state = 1;
            }
        }

        // While holding, cycle through states every 2 sec
        if (button == 0 && button_held) {
            if ((msTicks - cycle_state_timer) >= 2000) {
                state = (SystemState)(((int)state + 1) % STATE_MAX);
                if (state == OFF) state = 1;  // Skip OFF
                resetSections();
                cycle_state_timer = msTicks;
            }
        }

        // Button released
        if (button == 1 && lastButton == 0) {
            if (!button_held) {
                // Short press: toggle OFF
                if (state != OFF) {
                    last_active_state = state;
                    state = OFF;
                } else {
                    state = last_active_state;
                }
                resetSections();
            }
        }

        lastButton = button;
        
        if (state >= STATE_MAX) {
            state = OFF;
        }
        
        // Output logic
        switch (state) {
            case OFF:
            case STATE_MAX:
                resetSections();
                break;
            case RED_GREEN:
                SECTION_RED = 1;
                SECTION_GREEN = 1;
                break;
            case WHITE_01_10:
                SECTION_WHITE_01_10 = 1;
                break;
            case WHITE_11_16:
                SECTION_WHITE_11_16 = 1;
                break;
            case FULL_COMBO:
                SECTION_RED = 1;
                SECTION_GREEN = 1;
                SECTION_WHITE_11_16 = 1;
                break;
            case ALL_WHITE:
                SECTION_WHITE_01_10 = 1;
                SECTION_WHITE_11_16 = 1;
                break;
            case ALL_WHITE_FLASH:
                SECTION_WHITE_01_10 = flashState;
                SECTION_WHITE_11_16 = flashState;
                break;
            case ALL_WHITE_SOS:
                SECTION_WHITE_01_10 = sosState;
                SECTION_WHITE_11_16 = sosState;
                break;
        }
    }
}

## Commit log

2025-05-16 Fix:laststeptime to global variable
    [BoatLight.ino]
2025-05-20 added various documentation
    [Sketch.fzz]
2025-05-20 refactored code to serveral messages various fixes due to testing added debug and wokwi switch
    [BoatLight.ino]
2025-05-21 added datasheets
    [Sketch.fzz]
2025-05-21 added led power switching added enum for light modes implemented save delay to EEPROM some minor code optimizations
2025-05-30 moved documents
    [Components.xlsx, Sketch.fzz]
2025-05-30 sketch update
    [Sketch.fzz]
2025-06-02 fix: outputstate nt set
    [BoatLight.ino]
2025-06-02 chore: added support for long and sort button press chore: state is stored with a delay of 2 seconds fix: outputstate not set correctly fix: updated sketch, measure voltage before diode chore: added 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
    [Sketch.fzz]
2025-06-03 updated voltage threshold only set voltage pin to high once do a sample read on the solar voltage updated sleep
2025-06-11 moved file
    [Sketch.fzz]
2025-08-07 added support for variable number of leds
2025-09-04 added extra on-off button mode button only toggles modes changed pressed state to highvarious refactoring and name changes
2025-09-23 fix: off by 1 fix: last save mode fix: shut down procedure
    [BoatLight.ino]
2025-10-07 feat: improve mode handling and on/off behavior
    - Skip OFF_MODE when cycling through modes with the mode button
    - Update on/off button logic:
    - When ON → pressing turns LEDs off but remembers last active mode
    - When OFF → pressing restores the last active mode before power off
    - Improve EEPROM saving logic to prevent unnecessary writes immediately
    after turning back on
    - Add reset timing after on/off toggle to ensure stable mode restore
    [BoatLight.ino]
2025-11-10 - removed fading from sos - added flash mode - refactored mode count - added function declarations - refactored initialize button function to one implementation - added test at init for led strip - s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
    [BoatLight.ino]
2025-12-15 - fix: lowered upper threshold
    [BoatLight.ino]
2026-01-08 - ran prettier - added support for sos button - removed support for power pin
2026-01-08 - prevent floating of input button
    [BoatLight.ino]
